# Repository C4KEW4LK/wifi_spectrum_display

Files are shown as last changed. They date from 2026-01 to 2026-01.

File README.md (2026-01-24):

# WiFi Spectrum Display

A WiFi spectrum analyzer for ESP32-C3 that visualizes 2.4GHz WiFi activity on a NeoPixel LED strip. Monitor packet traffic or signal strength across all 13 WiFi channels in real-time.

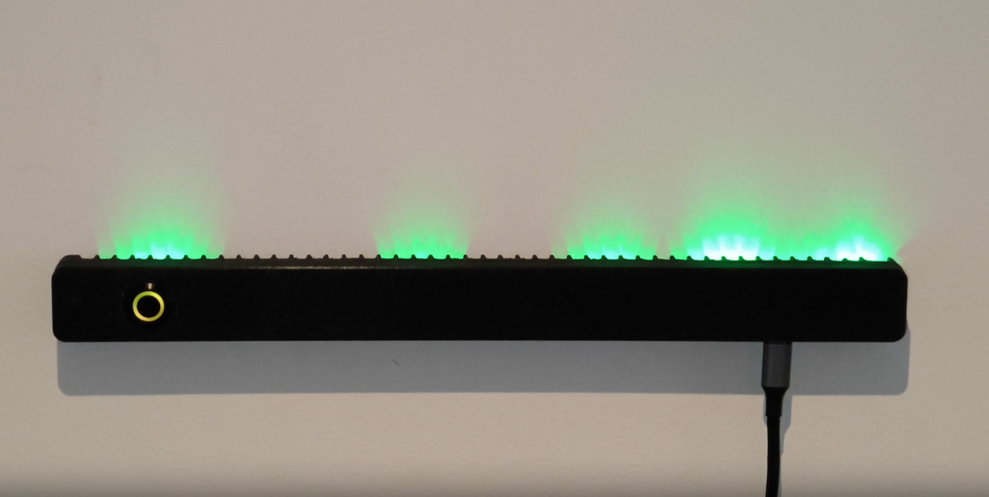
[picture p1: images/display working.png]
Device Photo


Layout Diagram

## Features

- **Two Scan Modes**
  - **Traffic Mode**: Passively monitors packet traffic per channel
  - **RSSI Mode**: Scans for access points and displays signal strength

- **Display Modes**
  - Solid color with adjustable hue/saturation
  - Colormaps (Jet, HSV, Autumn, Hot, Cool, Viridis, Plasma, Turbo)
  - Rainbow scroll
  - Cycling color

- **Web Configuration UI**
  - Connect to the device's WiFi AP to configure settings
  - Real-time preview of changes
  - Captive portal auto-opens settings page

- **Persistent Settings**
  - All settings saved to flash memory
  - Survives reboots

- **Button Controls**
  - Short press: Cycle display mode
  - Double press: Toggle WiFi AP for settings
  - Long press (3s): Power on/off

- **RGB Button LED**
  - White breathing: Normal operation
  - Solid blue: AP mode active
  - Off: Powered down

## Hardware

### Components

| Component |QTY. | Description | Example Online Source |
|---|---|---|---|
| SeeedStudio Xiao ESP32-C3 | 1| Main microcontroller | https://www.seeedstudio.com/Seeed-XIAO-ESP32C3-p-5431.html|
| WS2812B Strip |1| 144led/m IP30 (i.e. no covering) ~30cm strip, usually sold per meter | https://www.aliexpress.com/item/1005009096063569.html|
| Momentary Button with RGB LED |1| Common cathode button LED 5v 16mm low profile momentary |https://www.aliexpress.com/item/4001160061412.html|
| M2.5X16mm  screws |5| Countersunk head |https://www.aliexpress.com/item/32946954901.html|
| M2.5X8mm  screws |2| Countersunk head |https://www.aliexpress.com/item/32946954901.html|

Some wire for connecting all the parts.

### Wiring

| Function | GPIO Pin |
|---|---|
| NeoPixel Data | 8 |
| Button | 5 |
| Button LED Red | 4 |
| Button LED Green | 3 |
| Button LED Blue | 2 |

Connect NeoPixel VCC to 5V and GND to GND.

### 3D Printed Enclosure

Print files are located in the `3D prints` folder. The model is already oriented for printing and no supports are necessary. I think 0.15-0.2mm layer height is good. The screws are meant to thread there own holes 

## Software Setup

### Dependencies

Install these libraries via Arduino Library Manager:

- **FastLED** - NeoPixel control
- **WebServer** - Built-in with ESP32
- **DNSServer** - Built-in with ESP32
- **Preferences** - Built-in with ESP32
- **ArduinoOTA** - Built-in with ESP32

### Installation

1. Install [Arduino IDE](https://www.arduino.cc/en/software) or PlatformIO
2. Add ESP32 board support (Arduino ESP32 core)
3. Install the FastLED library
4. Open `wifi_spectrum_display/wifi_spectrum_display.ino`
5. Select your ESP32-C3 board
6. Upload

## Usage

### First Boot

1. Power on the device
2. The LED strip will show a startup animation
3. The button LED will breathe white

### Accessing Settings

1. Double-press the button (LED turns blue)
2. Connect to WiFi network: `WiFi-Spectrum`
3. Password: `spectrum123`
4. Settings page should open automatically (if not go to http://192.168.4.1)
5. Configure display mode, colors, brightness, etc.
6. Click "Save & Exit" or double-press button to save and close AP

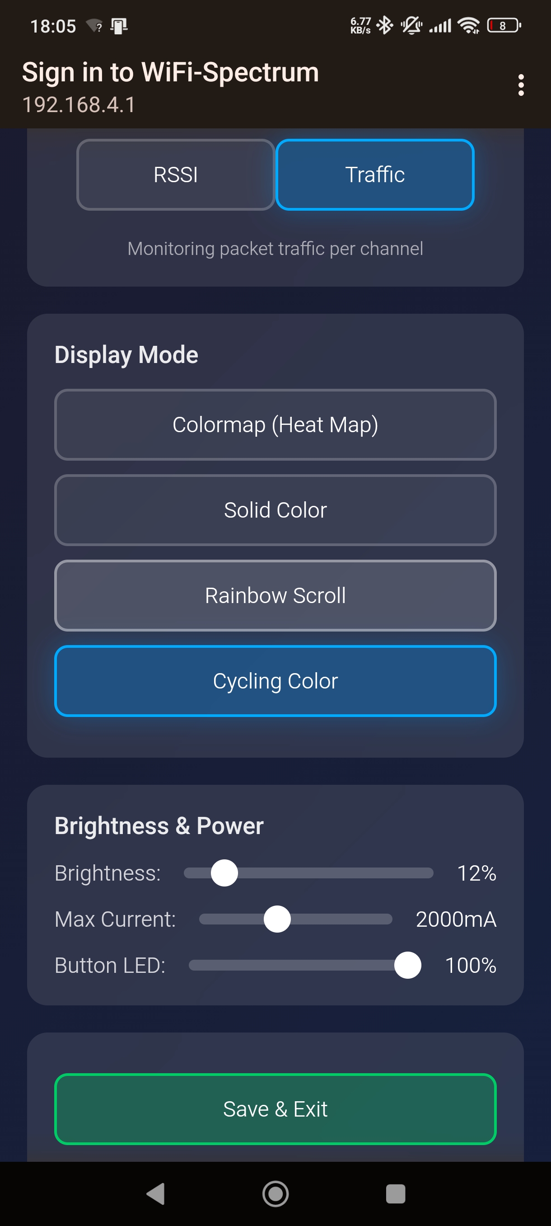
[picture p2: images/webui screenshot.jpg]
Web UI Screenshot


### Settings

| Setting | Description |
|---|---|
| Display Mode | Solid Color, Colormap, Rainbow Scroll, Cycling Color |
| Scan Mode | RSSI (signal strength) or Traffic (packet count) |
| Colormap | Choose from 8 scientific colormaps |
| Solid Color | Hue and saturation for solid color mode |
| Brightness | NeoPixel strip brightness (0-100%) |
| Button LED | Button LED brightness (0-100%) |
| Max Current | Power limiting for LED strip (100-5000mA) |

### OTA Updates

The device supports over-the-air updates when the AP is active:

- Hostname: `wifi-spectrum`
- Password: `spectrum123`

## How It Works

### Traffic Mode (Default)

The ESP32 enters WiFi promiscuous mode and passively listens for all WiFi packets on each channel. It hops through all 13 channels, counting packets on each. Channels with more traffic appear brighter on the LED strip.

This is completely passive - no packets are transmitted.

### RSSI Mode

The ESP32 scans for nearby access points and maps their signal strength to the LED strip based on which channel they're on. Stronger signals appear brighter.

### LED Mapping

The LEDs are mapped across 13 WiFi channels using a Gaussian kernel for smooth blending between adjacent channels. Each channel's activity spreads across multiple LEDs with a bell-curve distribution. The design targets 46 LEDs, but this can be adjusted via `NUM_LEDS` in the code.

## Configuration

Key settings in the code (`wifi_spectrum_display.ino`):

```cpp
#define NUM_LEDS          46      // Number of NeoPixels
#define CHANNEL_HOP_MS    10      // Time per channel in traffic mode
#define DECAY_FACTOR      0.95f   // LED brightness decay rate
#define LONG_PRESS_MS     3000    // Long press duration
```

WiFi AP settings:
```cpp
const char* AP_SSID = "WiFi-Spectrum";
const char* AP_PASS = "spectrum123";
```

## License

MIT License - Feel free to use and modify.

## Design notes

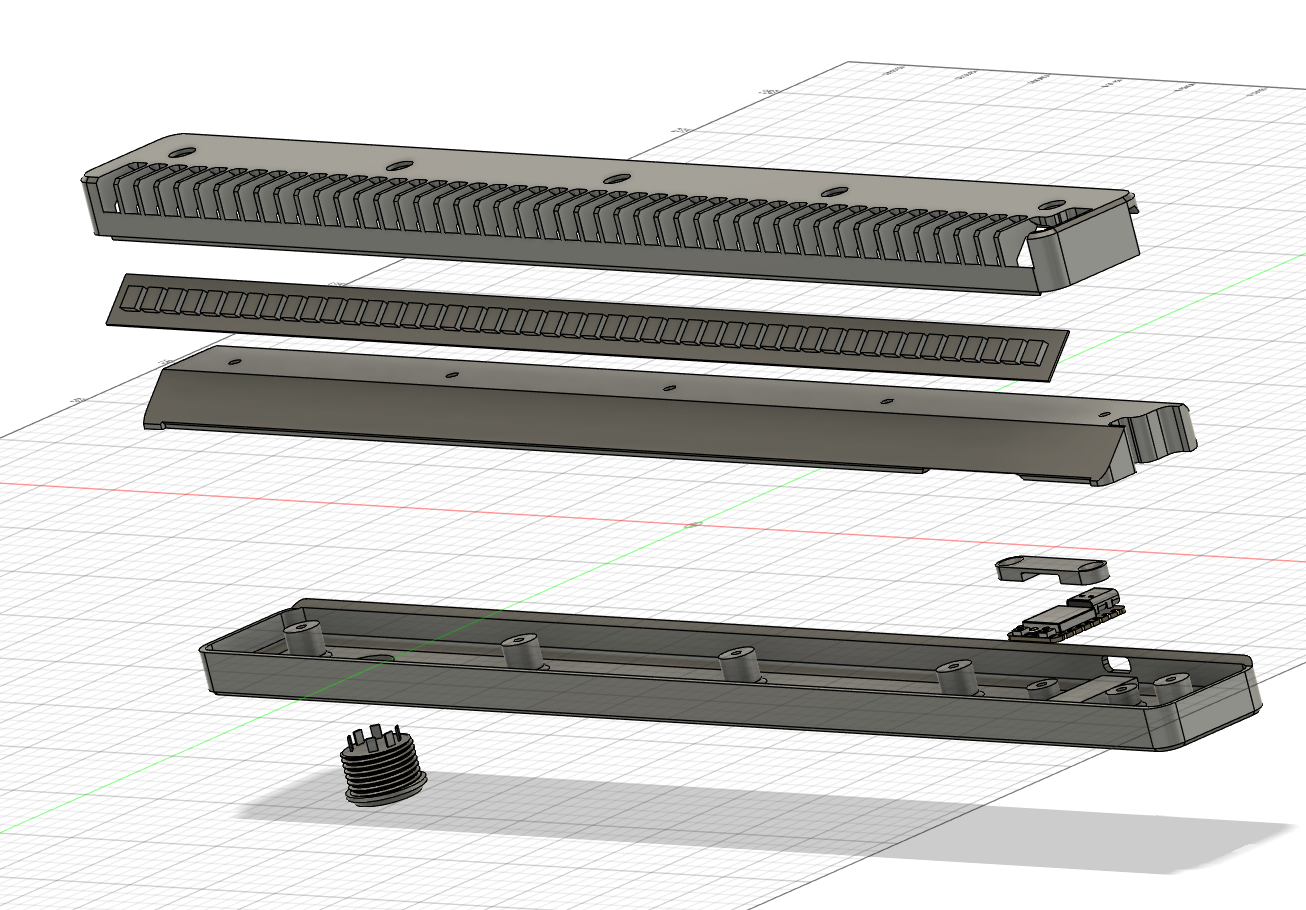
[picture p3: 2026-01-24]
images/exploded view.png

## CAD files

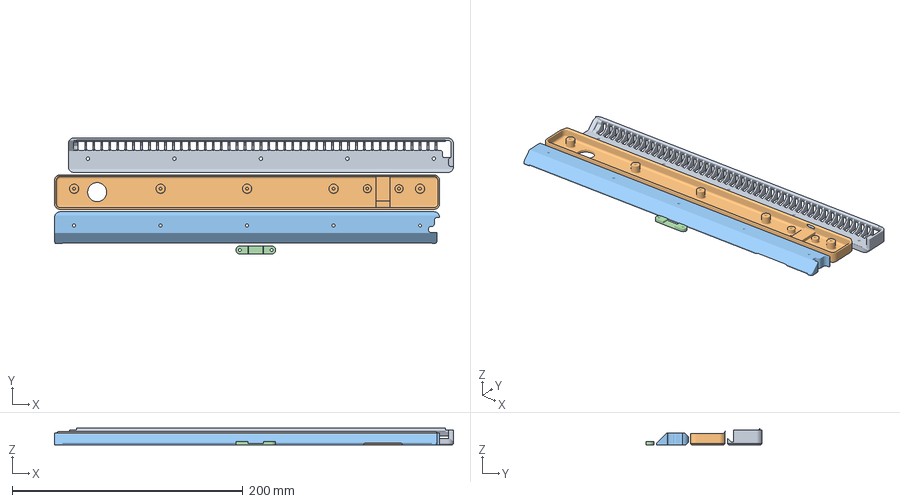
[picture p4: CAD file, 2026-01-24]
3D prints/esp32 wifi display.3mf
346.0 x 100.7 x 14.5 mm
back plate
front plate
mid plate (1)
esp32 clamp

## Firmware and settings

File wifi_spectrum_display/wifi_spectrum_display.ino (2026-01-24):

/*
 * WiFi Spectrum Display for ESP32-C3
 *
 * Scans 2.4GHz WiFi channels and displays signal strength on NeoPixels.
 * Includes a web UI for selecting display modes and colors.
 *
 * Hardware:
 *   - ESP32-C3 board
 *   - WS2812B NeoPixel strip (50 LEDs)
 *   - Connect NeoPixel DATA to GPIO 8
 *   - Connect NeoPixel VCC to 5V, GND to GND
 *
 * Web UI:
 *   - Connect to WiFi AP "WiFi-Spectrum" (password: "spectrum123")
 *   - Open http://192.168.4.1 in browser
 *
 * Libraries required:
 *   - FastLED
 *   - WebServer (built-in with ESP32)
 */

#include <WiFi.h>
#include <WebServer.h>
#include <DNSServer.h>
#include <ArduinoOTA.h>
#include <FastLED.h>
#include <Preferences.h>
#include "esp_wifi.h"

// Sine lookup table for breathing effect (64 entries, 0-255 range)
const uint8_t BREATHING_LUT[64] = {
  128, 140, 152, 165, 176, 188, 198, 208,
  218, 226, 234, 240, 245, 250, 253, 255,
  255, 255, 253, 250, 245, 240, 234, 226,
  218, 208, 198, 188, 176, 165, 152, 140,
  128, 115, 103,  90,  79,  67,  57,  47,
   37,  29,  21,  15,  10,   5,   2,   0,
    0,   0,   2,   5,  10,  15,  21,  29,
   37,  47,  57,  67,  79,  90, 103, 115
};

Preferences preferences;

// =============================================================================
// CONFIGURATION
// =============================================================================

#define NEOPIXEL_PIN      8
#define BUTTON_PIN        5       // Button to toggle AP/web UI mode (pull-up, active LOW)
#define BUTTON_LED_R      4       // RGB button LED - Red
#define BUTTON_LED_G      3       // RGB button LED - Green
#define BUTTON_LED_B      2       // RGB button LED - Blue
#define NUM_CHANNELS      13
#define NUM_LEDS          46

#define LONG_PRESS_MS     3000    // Hold time for long press (power off)
#define DOUBLE_PRESS_MS   400     // Max time between presses for double press
#define DEBOUNCE_MS       50      // Button debounce time

#define SCAN_DELAY_MS     33
#define BRIGHTNESS        255

#define RSSI_MIN          -90
#define RSSI_MAX          -30

// Traffic monitoring settings
#define CHANNEL_HOP_MS    10       // Time to listen on each channel (~25 updates/s)
#define PACKETS_PER_MS    2       // Expected packets/ms on a busy channel
#define PACKETS_MIN       0       // Min packets for display scaling
#define PACKETS_MAX       (CHANNEL_HOP_MS * PACKETS_PER_MS)  // Auto-scaled to hop time

// Gaussian kernel for LED spread
#define KERNEL_RADIUS     6        // Kernel extends ±6 pixels from center
#define KERNEL_SIZE       (2 * KERNEL_RADIUS + 1)

// Decay settings
#define DECAY_INTERVAL_MS 20       // How often decay runs (independent of packet updates)
#define DECAY_FACTOR      0.95f     // Multiply brightness by this each tick (exponential decay)

// WiFi AP settings
const char* AP_SSID = "WiFi-Spectrum";
const char* AP_PASS = "spectrum123";

// OTA settings
const char* OTA_HOSTNAME = "wifi-spectrum";
const char* OTA_PASSWORD = "spectrum123";

// =============================================================================
// Display modes
// =============================================================================

enum DisplayMode {
  MODE_SOLID_COLOR,      // User-selected color, brightness = signal
  MODE_COLORMAP,         // Colormap based on RSSI
  MODE_RAINBOW_SCROLL,   // Scrolling rainbow, brightness = signal
  MODE_CYCLING_COLOR     // Single hue that cycles, brightness = signal
};

enum Colormap {
  CMAP_JET,              // Blue -> Cyan -> Green -> Yellow -> Red
  CMAP_HSV,              // Full rainbow
  CMAP_AUTUMN,           // Red -> Orange -> Yellow
  CMAP_HOT,              // Black -> Red -> Yellow -> White
  CMAP_COOL,             // Cyan -> Magenta
  CMAP_VIRIDIS,          // Purple -> Blue -> Green -> Yellow
  CMAP_PLASMA,           // Purple -> Pink -> Orange -> Yellow
  CMAP_TURBO,            // Improved rainbow (Google's turbo)
  CMAP_COUNT             // Number of colormaps
};

enum ScanMode {
  SCAN_RSSI,             // Scan for APs and show signal strength
  SCAN_TRAFFIC           // Monitor packet traffic per channel
};

// =============================================================================
// Global variables
// =============================================================================

CRGB leds[NUM_LEDS];
int channelRSSI[NUM_CHANNELS];
volatile uint32_t channelPackets[NUM_CHANNELS];    // Packet counts per channel
uint32_t channelPacketsDisplay[NUM_CHANNELS];      // Display values for each channel
uint8_t ledDisplayBrightness[NUM_LEDS];            // Current brightness per LED (with decay)
float gaussianKernel[KERNEL_SIZE];                 // Pre-computed Gaussian kernel

// Dynamic packet scaling
uint32_t maxPacketsLastSecond = 1;                 // Max packets seen in last second (for scaling)
uint32_t currentSecondMaxPackets = 0;              // Max packets being tracked this second
unsigned long lastMaxReset = 0;                    // When we last reset the max tracker

// Dynamic RSSI scaling (over 10 seconds)
int rssiMin10s = -90;                              // Min RSSI seen in last 10s
int rssiMax10s = -30;                              // Max RSSI seen in last 10s
int currentRssiMin = 0;                            // Min being tracked this period
int currentRssiMax = -100;                         // Max being tracked this period
unsigned long lastRssiReset = 0;                   // When we last reset RSSI tracking

WebServer server(80);
DNSServer dnsServer;
const byte DNS_PORT = 53;

// Scan mode
ScanMode currentScanMode = SCAN_TRAFFIC;
uint8_t currentChannel = 1;
unsigned long lastChannelHop = 0;
bool promiscuousEnabled = false;

// Display settings
DisplayMode currentMode = MODE_SOLID_COLOR;
Colormap currentColormap = CMAP_JET;
uint8_t solidHue = 64;        // HSV hue for solid color (0-255) - pure yellow
uint8_t solidSat = 255;       // HSV saturation
uint8_t rainbowOffset = 0;    // For scrolling rainbow
uint8_t cyclingHue = 0;       // For cycling color mode
uint8_t maxBrightness = 255;  // Global brightness limit (0-255)
uint8_t buttonLedBrightness = 255;  // Button LED brightness (0-255)
uint16_t maxMilliamps = 2000; // Max current in mA (for power limiting)

// Timing
unsigned long lastScan = 0;
unsigned long lastAnimation = 0;
unsigned long lastDecay = 0;

// Button state
unsigned long buttonPressStart = 0;
unsigned long lastDebounceTime = 0;
bool lastButtonState = HIGH;
bool debouncedState = HIGH;
bool buttonHandled = false;
bool apEnabled = false;
bool powerOn = true;                // Power state (long press toggles)

// =============================================================================
// Web UI HTML
// =============================================================================

const char HTML_PAGE[] PROGMEM = R"rawliteral(
<!DOCTYPE html>
<html>
<head>
  <meta name="viewport" content="width=device-width, initial-scale=1">
  <title>WiFi Spectrum Display</title>
  <style>
    * { box-sizing: border-box; }
    body {
      font-family: -apple-system, BlinkMacSystemFont, 'Segoe UI', Roboto, sans-serif;
      background: linear-gradient(135deg, #1a1a2e 0%, #16213e 100%);
      color: #fff;
      margin: 0;
      padding: 20px;
      min-height: 100vh;
    }
    .container {
      max-width: 400px;
      margin: 0 auto;
    }
    h1 {
      text-align: center;
      font-size: 1.5em;
      margin-bottom: 30px;
      text-shadow: 0 0 20px rgba(0,150,255,0.5);
    }
    .card {
      background: rgba(255,255,255,0.1);
      border-radius: 15px;
      padding: 20px;
      margin-bottom: 20px;
      backdrop-filter: blur(10px);
    }
    .card h2 {
      margin-top: 0;
      font-size: 1.1em;
      opacity: 0.9;
    }
    .mode-btn {
      display: block;
      width: 100%;
      padding: 15px;
      margin: 10px 0;
      border: 2px solid rgba(255,255,255,0.2);
      border-radius: 10px;
      background: rgba(255,255,255,0.05);
      color: #fff;
      font-size: 1em;
      cursor: pointer;
      transition: all 0.3s;
    }
    .mode-btn:hover {
      background: rgba(255,255,255,0.15);
      border-color: rgba(255,255,255,0.4);
    }
    .mode-btn.active {
      background: rgba(0,150,255,0.3);
      border-color: #0af;
      box-shadow: 0 0 20px rgba(0,150,255,0.3);
    }
    .color-picker-wrap {
      display: flex;
      align-items: center;
      gap: 15px;
      margin-top: 15px;
    }
    .color-picker-wrap label {
      opacity: 0.8;
    }
    input[type="color"] {
      width: 60px;
      height: 40px;
      border: none;
      border-radius: 8px;
      cursor: pointer;
      background: none;
    }
    input[type="range"] {
      flex: 1;
      height: 8px;
      border-radius: 4px;
      -webkit-appearance: none;
      background: rgba(255,255,255,0.2);
    }
    input[type="range"]::-webkit-slider-thumb {
      -webkit-appearance: none;
      width: 20px;
      height: 20px;
      border-radius: 50%;
      background: #fff;
      cursor: pointer;
    }
    .status {
      text-align: center;
      opacity: 0.6;
      font-size: 0.9em;
      margin-top: 20px;
    }
    #colorSection, #colormapSection {
      display: none;
    }
    .preview {
      height: 30px;
      border-radius: 8px;
      margin-top: 10px;
      background: linear-gradient(90deg, #f00, #ff0, #0f0, #0ff, #00f, #f0f, #f00);
    }
    #solidPreview {
      background: hsl(0, 100%, 50%);
    }
    .cmap-btn {
      display: inline-block;
      padding: 10px 12px;
      margin: 5px;
      border: 2px solid rgba(255,255,255,0.2);
      border-radius: 8px;
      background: rgba(255,255,255,0.05);
      color: #fff;
      font-size: 0.9em;
      cursor: pointer;
      transition: all 0.3s;
    }
    .cmap-btn:hover {
      background: rgba(255,255,255,0.15);
    }
    .cmap-btn.active {
      background: rgba(0,150,255,0.3);
      border-color: #0af;
    }
    .cmap-grid {
      display: flex;
      flex-wrap: wrap;
      justify-content: center;
    }
    .cmap-preview {
      height: 6px;
      border-radius: 3px;
      margin-top: 5px;
    }
    .cmap-jet { background: linear-gradient(90deg, #000080, #00f, #0ff, #ff0, #f00); }
    .cmap-hsv { background: linear-gradient(90deg, #f00, #ff0, #0f0, #0ff, #00f, #f0f, #f00); }
    .cmap-autumn { background: linear-gradient(90deg, #f00, #f80, #ff0); }
    .cmap-hot { background: linear-gradient(90deg, #000, #f00, #ff0, #fff); }
    .cmap-cool { background: linear-gradient(90deg, #0ff, #f0f); }
    .cmap-viridis { background: linear-gradient(90deg, #440154, #3b528b, #21918c, #5ec962, #fde725); }
    .cmap-plasma { background: linear-gradient(90deg, #0d0887, #7e03a8, #cc4778, #f89540, #f0f921); }
    .cmap-turbo { background: linear-gradient(90deg, #30123b, #4686e1, #2ddcba, #f9dc2a, #e5500e, #7a0403); }
  </style>
</head>
<body>
  <div class="container">
    <h1>WiFi Spectrum Display</h1>

    <div class="card">
      <h2>Scan Mode</h2>
      <div class="cmap-grid">
        <button class="mode-btn scan-btn" data-scan="0" onclick="setScan(0)" style="display:inline-block;width:45%">
          RSSI
        </button>
        <button class="mode-btn scan-btn" data-scan="1" onclick="setScan(1)" style="display:inline-block;width:45%">
          Traffic
        </button>
      </div>
      <div class="status" style="margin-top:10px;font-size:0.85em" id="scanInfo">
        Scanning access points
      </div>
    </div>

    <div class="card">
      <h2>Display Mode</h2>
      <button class="mode-btn" data-mode="1" onclick="setMode(1)">
        Colormap (Heat Map)
      </button>
      <button class="mode-btn" data-mode="0" onclick="setMode(0)">
        Solid Color
      </button>
      <button class="mode-btn" data-mode="2" onclick="setMode(2)">
        Rainbow Scroll
      </button>
      <button class="mode-btn" data-mode="3" onclick="setMode(3)">
        Cycling Color
      </button>
    </div>

    <div class="card" id="colorSection">
      <h2>Color Selection</h2>
      <div class="color-picker-wrap">
        <label>Hue:</label>
        <input type="range" id="hueSlider" min="0" max="255" value="0" oninput="setColor()">
      </div>
      <div class="color-picker-wrap">
        <label>Saturation:</label>
        <input type="range" id="satSlider" min="0" max="255" value="255" oninput="setColor()">
      </div>
      <div id="solidPreview" class="preview"></div>
    </div>
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
void loop() {
  server.handleClient();
  ArduinoOTA.handle();
  checkButton();

  // Handle DNS for captive portal when AP is active
  if (apEnabled) {
    dnsServer.processNextRequest();
  }

  // Skip processing if powered off
  if (!powerOn) {
    return;
  }

  unsigned long now = millis();

  // Handle scanning based on mode (skip when AP is active)
  if (!apEnabled) {
    if (currentScanMode == SCAN_RSSI) {
      // RSSI mode: periodic WiFi scans
      if (now - lastScan >= SCAN_DELAY_MS) {
        lastScan = now;
        scanWiFi();
      }
    } else {
      // Traffic mode: channel hopping
      if (now - lastChannelHop >= CHANNEL_HOP_MS) {
        lastChannelHop = now;
        hopChannel();
      }
    }
  }

  // Update animations
  if (now - lastAnimation >= 30) {
    lastAnimation = now;

    if (currentMode == MODE_RAINBOW_SCROLL) {
      rainbowOffset += 2;
    }
    if (currentMode == MODE_CYCLING_COLOR) {
      cyclingHue += 1;
    }

    // Button LED breathing effect
    updateButtonBreathing();
  }

  // Decay LED brightness on its own timer (skip when AP active for preview)
  if (!apEnabled && now - lastDecay >= DECAY_INTERVAL_MS) {
    lastDecay = now;
    decayLEDs();
  }

  // Update max packets scaling every 10 seconds
  if (now - lastMaxReset >= 10000) {
    lastMaxReset = now;
    // Use current period's max, but keep a minimum of 1 to avoid divide-by-zero
    maxPacketsLastSecond = (currentSecondMaxPackets > 0) ? currentSecondMaxPackets : 1;
    currentSecondMaxPackets = 0;
  }

  // Update RSSI scaling every 10 seconds
  if (now - lastRssiReset >= 10000) {
    lastRssiReset = now;
    // Use tracked min/max, with sensible defaults if no data
    if (currentRssiMax > currentRssiMin) {
      rssiMin10s = currentRssiMin;
      rssiMax10s = currentRssiMax;
    }
    // Reset for next period
    currentRssiMin = 0;
    currentRssiMax = -100;
  }

  updateLEDs();
}

// =============================================================================
// WiFi Scanning (RSSI Mode)
// =============================================================================

void scanWiFi() {
  // Reset channel RSSI values
  for (int i = 0; i < NUM_CHANNELS; i++) {
    channelRSSI[i] = RSSI_MIN - 1;
  }

  // Perform WiFi scan (non-blocking would be better but adds complexity)
  int networksFound = WiFi.scanNetworks(false, true, false, 300);

  if (networksFound > 0) {
    for (int i = 0; i < networksFound; i++) {
      int channel = WiFi.channel(i);
      int rssi = WiFi.RSSI(i);

      if (channel >= 1 && channel <= NUM_CHANNELS) {
        if (rssi > channelRSSI[channel - 1]) {
          channelRSSI[channel - 1] = rssi;
        }
        // Track min/max for dynamic scaling
        if (rssi < currentRssiMin) currentRssiMin = rssi;
        if (rssi > currentRssiMax) currentRssiMax = rssi;
      }
    }
  }

  WiFi.scanDelete();

  // Apply Gaussian for all channels after scan
  for (int ch = 0; ch < NUM_CHANNELS; ch++) {
    applyChannelGaussian(ch);
  }
}

// =============================================================================
// Traffic Monitoring (Promiscuous Mode)
// =============================================================================

// Callback for each received packet
void IRAM_ATTR promiscuousCallback(void* buf, wifi_promiscuous_pkt_type_t type) {
  if (currentChannel >= 1 && currentChannel <= NUM_CHANNELS) {
    channelPackets[currentChannel - 1]++;
  }
}

void enableAP() {
  if (apEnabled) return;

  // Stop promiscuous mode - can't do proper scanning while AP is running
  stopPromiscuous();

  // Switch to AP mode using Arduino library
  WiFi.mode(WIFI_AP);
  WiFi.softAP(AP_SSID, AP_PASS);

  // Start DNS server for captive portal (redirect all domains to our IP)
  dnsServer.start(DNS_PORT, "*", WiFi.softAPIP());

  apEnabled = true;
  Serial.printf("AP enabled - connect to %s (192.168.4.1)\n", AP_SSID);
}

void disableAP() {
  if (!apEnabled) return;

  // Save settings to flash before disabling AP
  saveSettings();

  // Stop DNS server
  dnsServer.stop();

  // Disconnect AP and switch to NULL mode for pure monitor
  WiFi.softAPdisconnect(true);
  WiFi.mode(WIFI_STA);
  WiFi.disconnect();
  esp_wifi_set_mode(WIFI_MODE_NULL);
  apEnabled = false;
  Serial.println("AP disabled - back to NULL mode");

  // Restart promiscuous mode if in traffic scan mode
  if (currentScanMode == SCAN_TRAFFIC) {
    startPromiscuous();
  }
}

void startPromiscuous() {
  if (promiscuousEnabled) return;

  // Reset packet counts
  for (int i = 0; i < NUM_CHANNELS; i++) {
    channelPackets[i] = 0;
    channelPacketsDisplay[i] = 0;
  }

  // Set callback and enable promiscuous mode (no filter = capture all)
  esp_wifi_set_promiscuous_rx_cb(promiscuousCallback);
  esp_wifi_set_promiscuous(true);

  // Set initial channel
  currentChannel = 1;
  esp_wifi_set_channel(currentChannel, WIFI_SECOND_CHAN_NONE);

  promiscuousEnabled = true;
  Serial.println("Promiscuous mode enabled");
}

void stopPromiscuous() {
  if (!promiscuousEnabled) return;

  esp_wifi_set_promiscuous(false);
  promiscuousEnabled = false;
  Serial.println("Promiscuous mode disabled");
}

void printChannelStats() {
  for (int i = 0; i < NUM_CHANNELS; i++) {
    Serial.printf("ch%d:%lu", i + 1, channelPacketsDisplay[i]);
    if (i < NUM_CHANNELS - 1) Serial.print(",");
  }
  Serial.println();
}

void printRawPackets() {
  Serial.print("RAW: ");
  for (int i = 0; i < NUM_CHANNELS; i++) {
    Serial.printf("%lu", channelPackets[i]);
    if (i < NUM_CHANNELS - 1) Serial.print(",");
  }
  Serial.println();
}

void hopChannel() {
  // Update display value for the channel we just listened on (before hopping)
  int idx = currentChannel - 1;
  channelPacketsDisplay[idx] = channelPackets[idx];  // Direct assignment

  // Track max packets for dynamic scaling
  if (channelPacketsDisplay[idx] > currentSecondMaxPackets) {
    currentSecondMaxPackets = channelPacketsDisplay[idx];
  }

  channelPackets[idx] = 0;  // Reset for next cycle

  // Apply Gaussian to LEDs immediately for this channel
  applyChannelGaussian(idx);

  // Move to next channel
  currentChannel++;
  if (currentChannel > NUM_CHANNELS) {
    currentChannel = 1;
    // Print stats after each full sweep
    printChannelStats();
  }

  esp_wifi_set_channel(currentChannel, WIFI_SECOND_CHAN_NONE);
}

// =============================================================================
// Colormap Functions
// =============================================================================

// Helper: interpolate between two RGB colors
CRGB lerpRGB(CRGB a, CRGB b, uint8_t t) {
  return CRGB(
    a.r + ((b.r - a.r) * t >> 8),
    a.g + ((b.g - a.g) * t >> 8),
    a.b + ((b.b - a.b) * t >> 8)
  );
}

// Jet colormap: blue -> cyan -> green -> yellow -> red
CRGB colormapJet(uint8_t v) {
  if (v < 64) {
    return lerpRGB(CRGB(0, 0, 128), CRGB(0, 0, 255), v * 4);
  } else if (v < 128) {
    return lerpRGB(CRGB(0, 0, 255), CRGB(0, 255, 255), (v - 64) * 4);
  } else if (v < 192) {
    return lerpRGB(CRGB(0, 255, 255), CRGB(255, 255, 0), (v - 128) * 4);
  } else {
    return lerpRGB(CRGB(255, 255, 0), CRGB(255, 0, 0), (v - 192) * 4);
  }
}

// HSV colormap: full rainbow
CRGB colormapHSV(uint8_t v) {
  return CHSV(v, 255, 255);
}

// Autumn colormap: red -> orange -> yellow
CRGB colormapAutumn(uint8_t v) {
  return CRGB(255, v, 0);
}

// Hot colormap: black -> red -> yellow -> white
CRGB colormapHot(uint8_t v) {
  if (v < 85) {
    return CRGB(v * 3, 0, 0);
  } else if (v < 170) {
    return CRGB(255, (v - 85) * 3, 0);
  } else {
    return CRGB(255, 255, (v - 170) * 3);
  }
}

// Cool colormap: cyan -> magenta
CRGB colormapCool(uint8_t v) {
  return CRGB(v, 255 - v, 255);
}

// Viridis colormap: purple -> blue -> green -> yellow
CRGB colormapViridis(uint8_t v) {
  // Approximation of viridis
  if (v < 64) {
    return lerpRGB(CRGB(68, 1, 84), CRGB(59, 82, 139), v * 4);
  } else if (v < 128) {
    return lerpRGB(CRGB(59, 82, 139), CRGB(33, 145, 140), (v - 64) * 4);
  } else if (v < 192) {
    return lerpRGB(CRGB(33, 145, 140), CRGB(94, 201, 98), (v - 128) * 4);
  } else {
    return lerpRGB(CRGB(94, 201, 98), CRGB(253, 231, 37), (v - 192) * 4);
  }
}

// Plasma colormap: purple -> pink -> orange -> yellow
CRGB colormapPlasma(uint8_t v) {
  if (v < 64) {
    return lerpRGB(CRGB(13, 8, 135), CRGB(126, 3, 168), v * 4);
  } else if (v < 128) {
    return lerpRGB(CRGB(126, 3, 168), CRGB(204, 71, 120), (v - 64) * 4);
  } else if (v < 192) {
    return lerpRGB(CRGB(204, 71, 120), CRGB(248, 149, 64), (v - 128) * 4);
  } else {
    return lerpRGB(CRGB(248, 149, 64), CRGB(240, 249, 33), (v - 192) * 4);
  }
}
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
